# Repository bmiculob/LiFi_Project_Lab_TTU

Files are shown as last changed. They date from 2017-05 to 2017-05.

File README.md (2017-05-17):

# LiFi_Project_Lab_TTU
This a git repository containing source code as well as schematics for the Li-Fi project at Texas Tech.

Sponsored by Dr. Zhaoyang Fan
# System Operating Instructions.
1.	Adjust the transmitter and the receiver with the lens so that the light is focused on the photodiode on the receiver side.
	*	Transmitter LED is powered with 12 V
	*	Turn the transmitter microcontroller off so that the LED remains on when powered with 12 V
2.	Keep only one microcontroller plugged into the laptop whether it be the transmitter or receiver.
3.	Got the the command prompt and type the command "mode" to determine which COM port it is and write it down or memorize it.
4.	Do the same for the other microcontroller.
5.	Open both the transmitter and receiver UI.
6.	Configure the transmitter values so that the Serial Port and Baudrate (200000) are set. All other values should remain default.
7.	Configure the receiver values so that the Serial Port and Baudrate (230414) are set. All other values should remain default.
8.	Try the test signal and see that the receiver detects it.
	*	If the indicator doesn’t work then save the data to file and check it.
9.	For transmitting a file chose a file on the transmitter side by clicking the browse button.
10.	On the receiver side choose a file path to save by clicking the browse button.
	*	Every time the path is changed the UART connection must toggle from closed state to open state.
11.	Once both UI’s are configured click the transmit button on the transmitter side to transmit the file.
12.	Once it is verified that the receiver is done transmitting close the UART connection and check if the file transmitted successfully.
# Schematics
The jumpers are referenced from the chip side of the tiva microcontroller.
## Transmitter
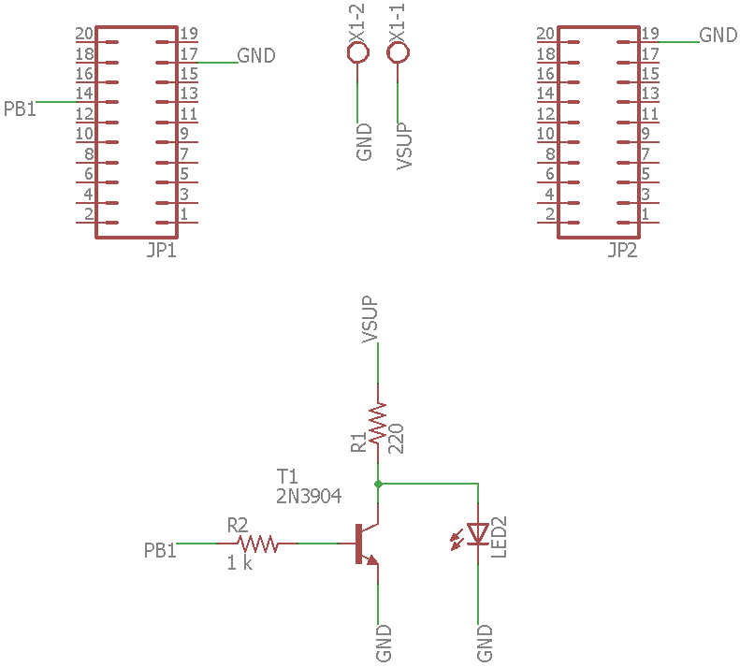
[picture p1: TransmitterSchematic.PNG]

## Receiver
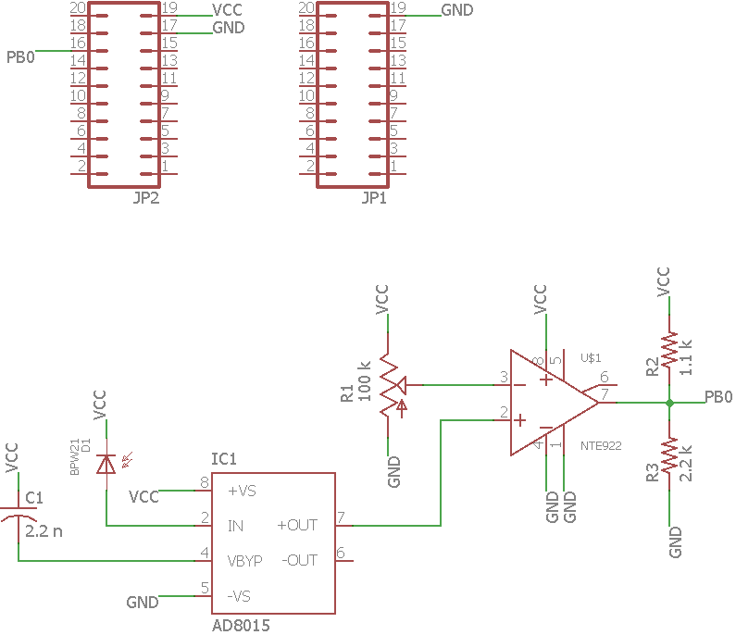
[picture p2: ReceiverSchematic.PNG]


[Transmitter]: https://github.com/soukoba/LiFi_Project_Lab_TTU/blob/master/TransmitterSchematic.PNG
[Receiver]: https://github.com/soukoba/LiFi_Project_Lab_TTU/blob/master/ReceiverSchematic.PNG

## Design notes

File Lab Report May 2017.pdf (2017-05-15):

Li-Fi Communication Prototype

Ben Miculob

IEEE # 93658299

Texas Tech University

May 2017

Sponsor Dr. Zhaoyang Fan

Group Members: Cody Cook, Joshua Bayer

Abstract

Li-Fi, an optical form of Wi-Fi communication, uses visible light to maintain

communication with other Li-Fi supported devices. A Li-Fi system consists of at least one

transmitter and one receiver. The transmitter is a system capable of sending signals through

visible light while the receiver is a system capable of receiving these signals. Li-Fi has the ability

to create wireless communication channels that will not interfere with RF frequencies.

Applicable use cases for Li-Fi would be in RF populated areas where RF is used to communicate

with equipment that is given the highest priority. The system discussed in this report focuses on

the On-Off keying modulation technique to communicate through one way transmission. There

will also be a focus on the hardware used to create the prototyped system.

Table of Contents

List of Figures

List of Tables

1 What is Li-Fi?

Li-Fi is a form of optical communication using visible light as a medium of for transferring

signals. Visible light, being a form of radiation between a wavelength of 400 nm and 700 nm,

can be an applicable medium for communication. It is naturally present within society, and can

possibly be an applicable alternative for communication. Visible light, has no chance of

interference with other signals outside its confined area. It can also be used in conjunction with

RF as these two will not interfere with each other. Advantageous applications for Li-Fi would be

on airplanes where visible light can supplement passengers with a connection to the internet

without interfering with needed communication that is installed on commercial airplanes.

Another use case would be in hospitals, as Li-Fi signals will not interfere with any medical

instruments such as MRI scanners. A good representation of the range of visible light is

illustrated in Figure 1. The numbers represent the wavelength in nanometers.

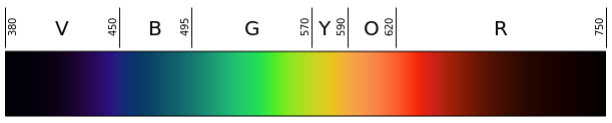
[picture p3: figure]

Figure 1: Visible Light Spectrum¹

1.1 Modulation Techniques

With Li-Fi, there are three different specifications of modulation techniques that are defined

by IEEE standards. These are the PHY, short for physical, layers called “PHY I,” “PHY II,” and

“PHY III.” This is with reference to the 7-layer OSI model used to represent network the tiers of

communication. PHY I is used for outdoor application and uses low data rates. The two main

1 By Gringer - Own work, Public Domain modulation techniques support on-off keying, and variable pulse position modulation. On-off

keying uses a sequence of high and low states to represent symbols encoded and decoded by the

symbols. In the case of PHY I, data rates go up to 100 kb/s with on off keying and use

Manchester encoded signals to send high and low states. Manchester encoded signals use

sequence of rising and falling edges to send high and low states. Figure 2 illustrates a timing

diagram demonstrating Manchester encoding. Two types of Manchester encoding are

demonstrated by this diagram. One follow’s G.E. Thomas’ encoding and the other representing

IEEE’s encoding.

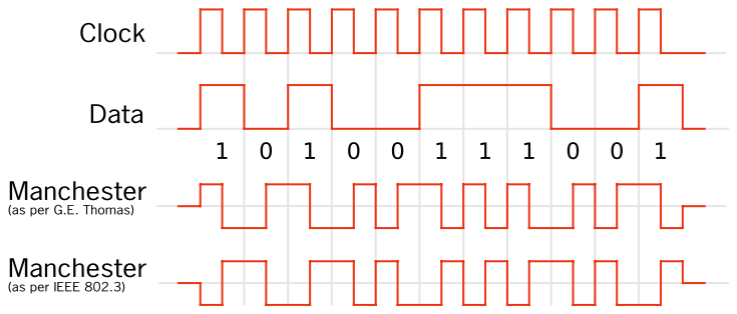
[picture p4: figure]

Figure 2: Manchester Encoding Timing Diagram Example¹

VPPM, or variable pulse position modulation, uses pulses in a specified time period to

represent high and low states in the system. These pulses are sent through the optical signal, and

the brightness of the signal determines how long the pulse must be. If the pulsed signal begins at

the start of the time period and ends between, then the represented symbol is a 0. If the pulsed

signal starts between the time period and stops at the end of the time period, then the represented

1 By Stefan Schmidt - Enhancement of Manchester Encoding, Public Domain state us a 1. Figure 3 shows a timing diagram of VPPM. This illustrates an example of different

brightness levels and their pulse lengths.

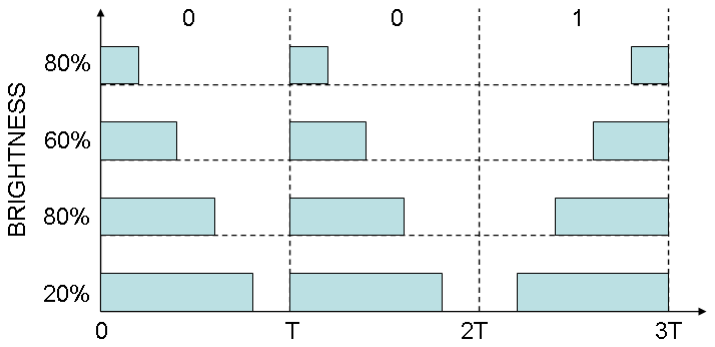
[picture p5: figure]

Figure 3: VPPM Encoding Timing Diagram Example¹

In the case of PHY I, VPPM data rates can go up to 266.6 kb/s using a 4B6B encoding.

4B6B takes 4 bit symbol and translates it into a 6 bit symbol. This is to ensure that there is an

even amount of 0’s and 1’s being sent through each encoded symbol. This helps with D.C.

balance allowing the prevention of an accumulation of charge across a coupling capacitor.

An example of a 4B6B pattern table is illustrated in Figure 4. In this case hexadecimal symbols

are translated into a 6 bit, binary pattern.

1 By gordonpovey

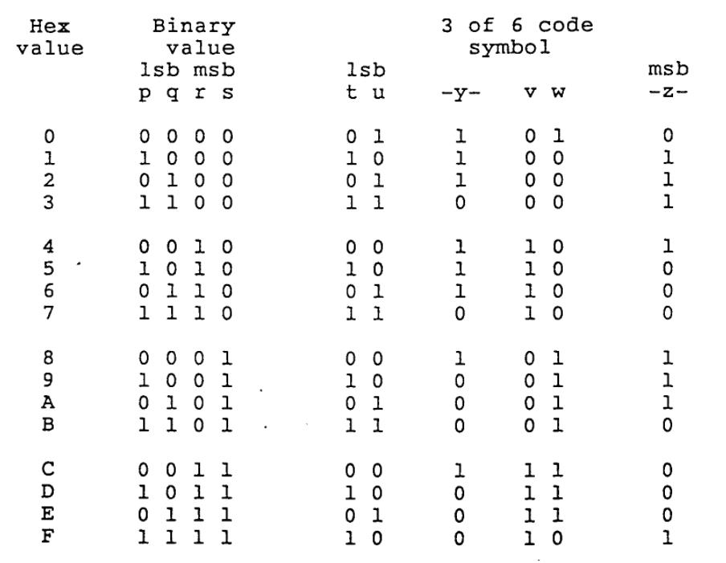
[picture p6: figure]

Figure 4: 4B6B Pattern Table¹

PHY II is used for indoor applications which also uses VPPM and OOK; however, these

have much higher data rates than PHY I. The data rates go up by an order of 10 being up to at

least 1.25 MB and up. In the case of VPPM, data rates go up to 1.25 Mb/s. With OOK, data rates

can go up to 96 Mb/s; however, on-off keying uses 8B10B encoding rather than Manchester.

8B10B is similar to 4B6B, the only difference being that it takes 8 bit patterns and translates

them into 10 bit patterns. PHY III layer is different in the case that it only uses one modulation

technique. Color shift keying is the main modulation technique used in PHY III. Its data rates

achieve a maximum speed similar to PHY II, but its initial clock rates are significantly lower.

PHY II’s minimum initial clock rate goes up to 120 MHz at its max speed, 96 Mb/s. PHY III’s

minimum clock rate goes up to 24 MHz at a max speed of 96 Mb/s. The reason that CSK is able

to achieve this is that CSK uses three channels of light to send symbols. Depending on the

1
From 4B6B Coding Scheme Patent sensitivity of the receiver, a CSK can ideally send a large amount of data at once. By encoding a

bit pattern into a color combination a CSK symbol can follow a set map of symbols. The length

of these symbols determine the type of CSK modulation used. The ones listed in the IEEE

standards are 4-CSK, or 2 bit symbols, 8- CSK, or 3 bit symbols, and 16-CSK, or 4 bit symbols.

An example of a CSK map is illustrated in Figure 5. This is shows a 16-CSK triangle being

mapped onto a color spectrum. The vertices are the primary colors red, green, and blue.

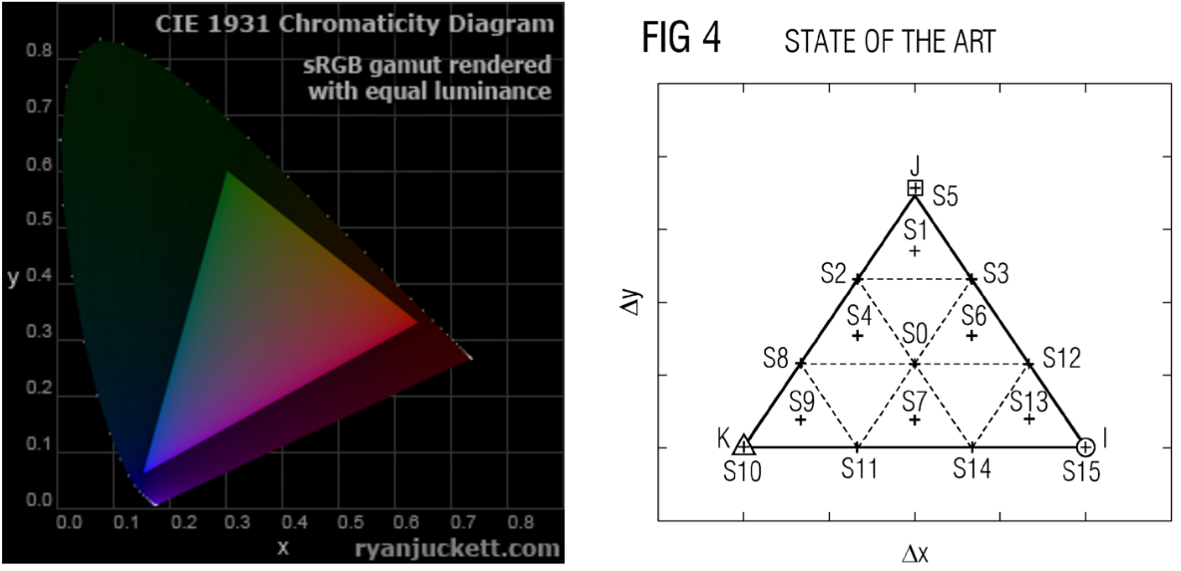
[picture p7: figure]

Figure 5: Color Map¹

and Bit Pattern Map²

The system that will be discussed focuses on on-off keying that does not use any of the

encoding standards listed in the PHY layers. The system will illustrate basic hardware and

communication between the transmitter and receiver. Techniques used in the listed PHY layers

are used as a basis for the discussed Li-Fi system. Tables 1, 2, and 3 describe all the PHY layers

and the modulation techniques used in each PHY layer.

1 PHY layer performance evaluation of the IEEE 802.15.7 visible light communication standard

2 Coding Scheme And Method For A Colour-Shift-Keying Constellation In A Visible-Light Communication System

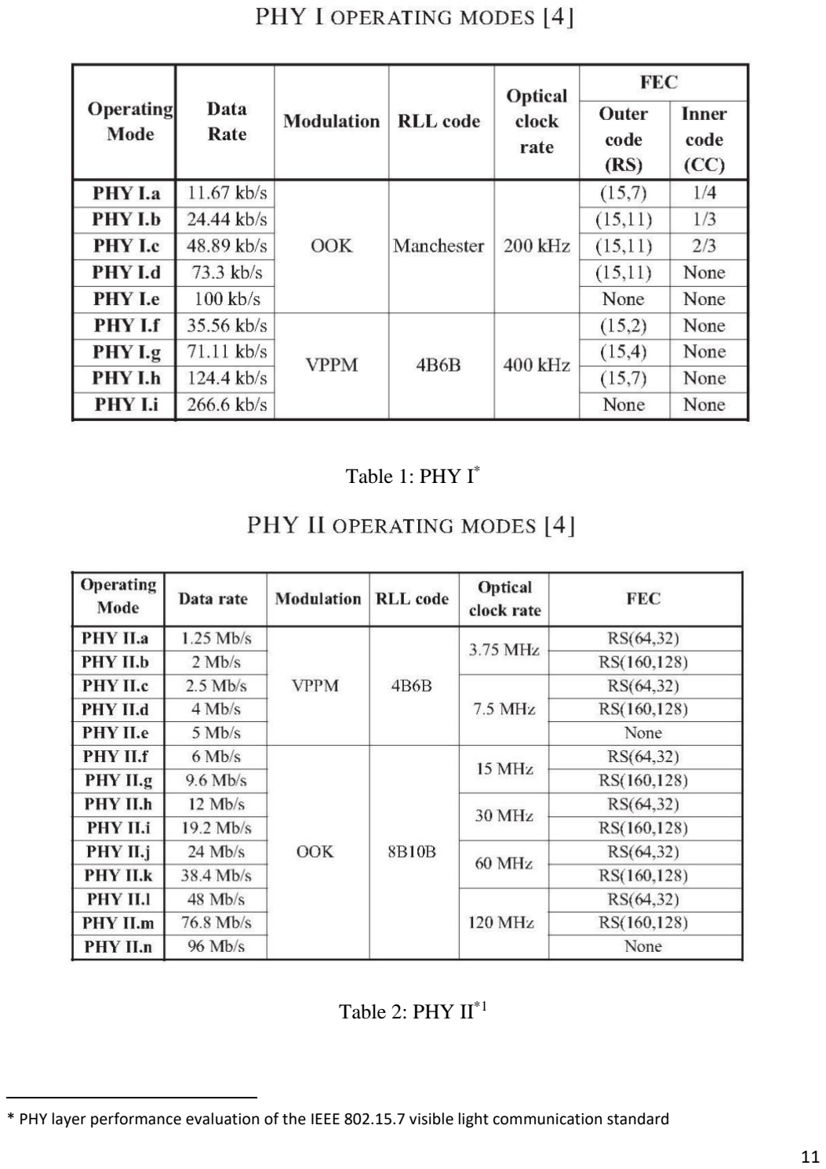
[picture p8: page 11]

Table 1: PHY I*

Table 2: PHY II*1

* PHY layer performance evaluation of the IEEE 802.15.7 visible light communication standard

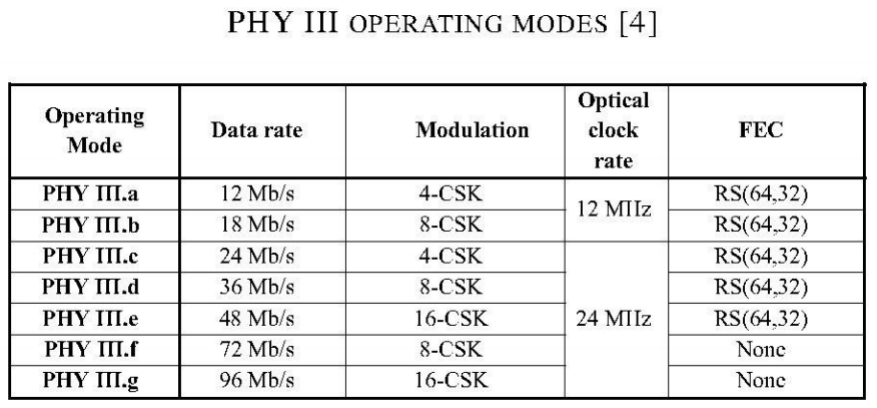
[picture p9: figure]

Table 3: PHY III*1

2 One-Way Li-Fi System

The system used to test Li-Fi communication consists of hardware only capable of one-way

communication. Creating the foundation of our prototype, the system built will test the validity

of transferring data through light. This can be tested with a simple transmitter and receiver. The

two main things required in the system is that it must be able to switch an LED, and the system

must be able to detect the LED pulses. Figure 6 illustrates a conceptual design of the system that

is considered.

* PHY layer performance evaluation of the IEEE 802.15.7 visible light communication standard

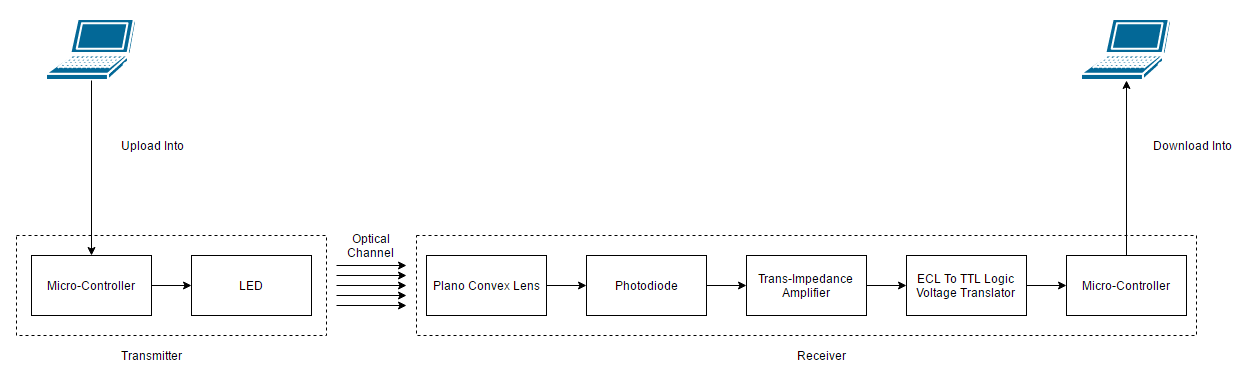
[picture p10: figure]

Figure 6: System Block Diagram

2.1 Transmitter LED Driving

Since Li-Fi uses pulsed signals to transmit data, the system must be capable of driving an

LED at a high rate. In this case, a transistor will be implemented to allow an adjustable voltage

signal to switch the LED while the supply voltage of the LED remains constant. Figure 7 shows

the schematic of the transmitter used in this system. The 220 Ω resistor limits the current going

into the LED, while it is supplied with a voltage of 12 V. Going into the base of the transistor is

the signal that will switch the LED. Our system uses a microcontroller to generate this 3.3 V

signal. The 1 kΩ resistor also acts as a current limiter for the signal. This schematic causes the

signal to be inverted, so when the signal sends a high, the LED turns off. When the signal sends a

low, the LED turns on.

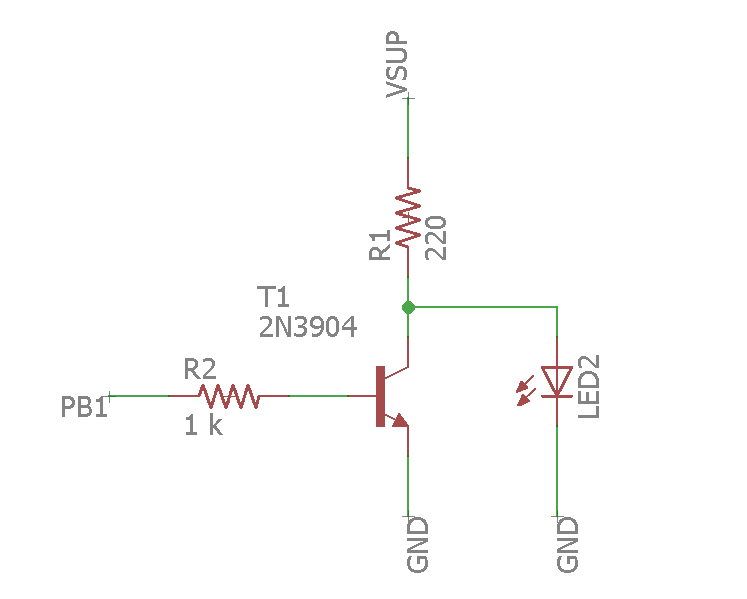
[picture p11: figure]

Figure 7: Switching LED Schematic

A board is also designed for this schematic so that it can be easily attached to a TI EK-

TM4C123GXL Launchpad, the microcontroller used in our system. Figure 8 shows the design

for this board. This board is designed for use with a square surface mount LED of about 2 mm in

length. The base is connected to PB1 of the micro controller, and pin 9 on JP1 and pin 10 on JP2

are grounded. The LED must be supplied by an independent voltage source. The dimensions are

shown in inches.

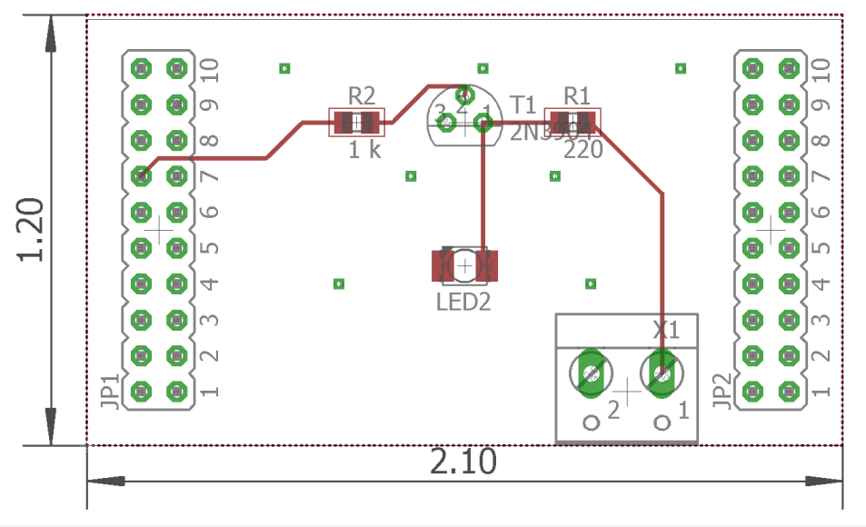
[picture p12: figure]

Figure 8: Switching LED PCB design

2.2 Receiver Photodetector

The system must be able to receive visible light signals and interpret them into signals that

the hardware will accept. A photodiode is used in this system as the photodetector for the

receiver. Figure 9 shows the schematic of the receiver used in the system. The photodiode is

reversed biased into the AD8015 which is a trans-impedance amplifier. The capacitor connected

to VBYP is used to take away noise from the power supply. According to the data sheet the

capacitor value must be chosen using formula 1. Where fmin is the minimum useful frequency.

(1) C1 >

1
2π×1000×fmin

The trans-impedance amplifier is takes the current generated by the photodiode and outputs a

differential voltage. One of the outputs of the differential is then fed into a comparator to

translate it into a logic voltage that can be used by a microcontroller. The potentiometer is used

to tune the reference voltage of the comparator. With this tested system, the voltage output of the

differential output oscillates between 3.7 V and 4.2V. The reference voltage is tuned between

these voltages to create a usable logic output. This is an open-drain comparator, so when the signal in the non-inverting output is higher than the reference voltage then the output signal is

pulled to ground. When the input signal is lower than the reference voltage then the output

voltage is voltage divided by R2 and R3. When used in conjunction with the transmitter circuit

described previously, this cancels out the inverted signal generated by the transmitter.

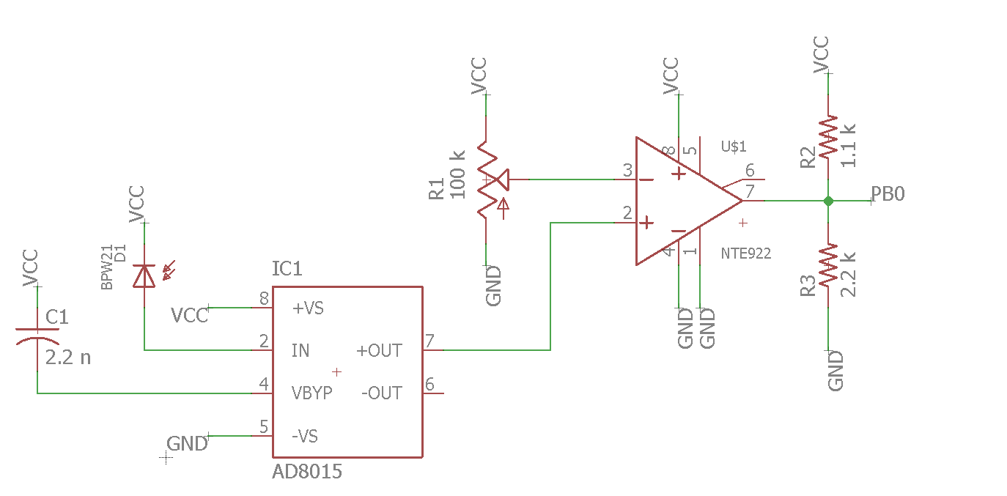
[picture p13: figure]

Figure 9: Receiver Schematic

The board design of the receiver schematic is designed while considering the pin layout

of the TI EK-TM4C123GXL Launchpad. Figure 10 shows the board design of the receiver

schematic. The circuit is powered by the microcontroller which outputs 5 V from pin 10 on JP2.

The left side of pin 8 on JP2 is where the logic is fed into from the receiver. Pin 9 on JP2 and pin

10 on JP10 are connected to the ground planes on the PCB. The board was designed for use with

a photodiode with a TO-5 package.

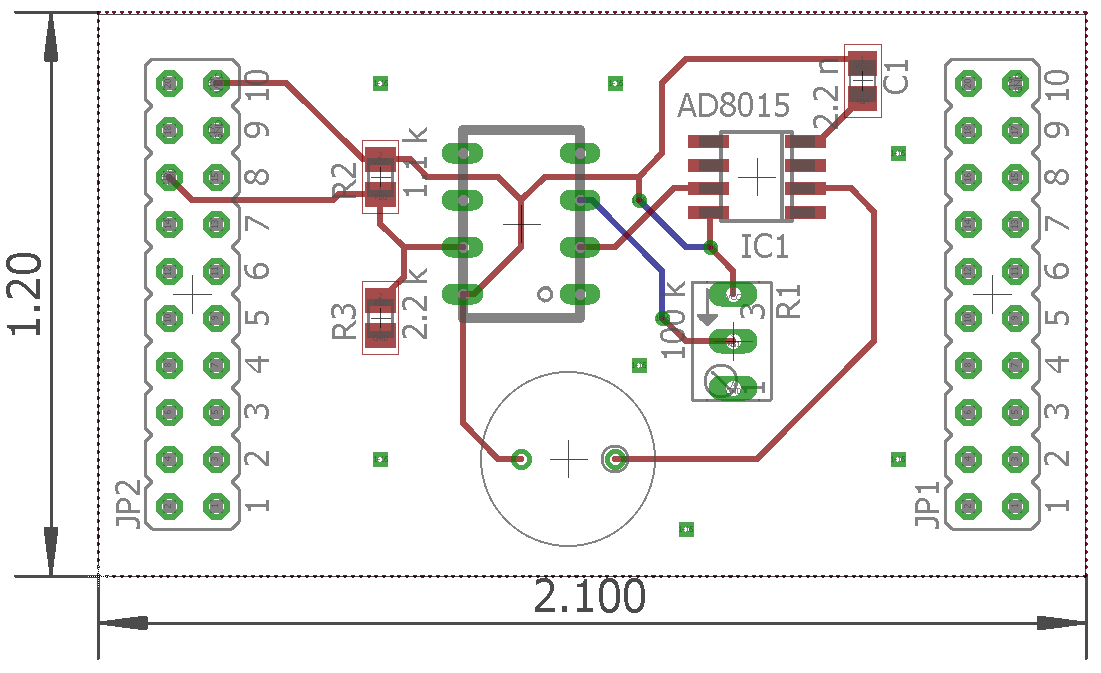
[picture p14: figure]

Figure 10: Receiver PCB Design

2.3 Microcontroller System

The current system utilizes two identical microcontrollers which are the TI EK-

TM4C123GXL Launchpad. One microcontroller drives the LED on the switching hardware. The

other will interpret the visible light signals translated from the receiver hardware. Each of them

are connected to system storage device, or a PC in this case, via a USB cord. Each Launchpad

houses a TM4C123GH6PM microcontroller, capable of generating and receiving signals in this

system. Figure 11 displays the microcontroller that is being used.

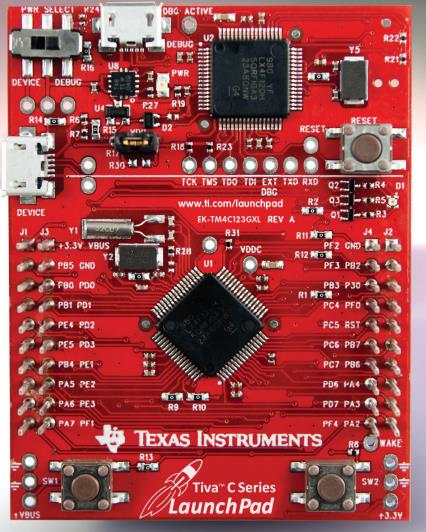
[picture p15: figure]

Figure 11: TM4C123GXL Launchpad¹

3 Communication Between System Storages and Prototyped System

Both of these microcontrollers are connected via USB to a large system storage. In this case,

a PC loaded with a Windows 10 operating system. The communication protocol used between

these components is UART. UART uses on-off keying to send packets of bits through a data

stream. UART is configured at a specific baud rate which is the amount of symbols that are sent

per period of time. Connection between the PC, microcontroller, and transmitter/receiver all use

the UART communication protocol. Figure 12 shows a simple timing diagram of 8 bit UART

communication. The start bit is a low signal for the specified time period. The stop bit is a high

signal for a specified time period. The stop bit length can be either 1, 1.5, or 2 times the time

period per bit of data.

1
From the Tiva LaunchPad Evaluation Kit PDF

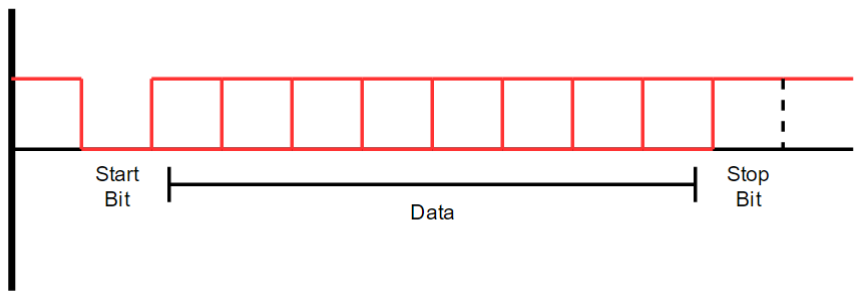
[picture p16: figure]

Figure 12: UART Diagram

Regarding the software within the microcontroller on the receiver and transmitter, there is

a queue that acts as a buffer for the data. Since the UART uses the FIFO method of sending data,

a queue is an applicable data structure for streaming bits. As bits of data are loaded into the

queue, those bits are then outputted to the specified system. Data will output into either the

transmitter, or the system storage. Figure 13 shows an example of the queue data structure. There

are head and tail indexes. The head shows where the next data should be place, while the tail

shows which data should be sent next.

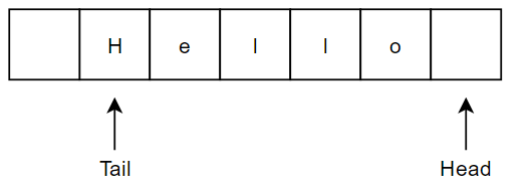
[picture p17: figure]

Figure 13: Queue Data Structure

3.1 System Data to Transmitter Output

Using the communication protocol implemented, the user will be able to load data into the

transmitter via the UART communication protocol. Since a file, at its most basic components, is a sequence of binary patterns, translating the data into a signal is not complex. The system is able

to take the file as is, and translate it to an on-off keying sequence. Data is read through in

sections of bytes, so the UART communication will send the data in packets of 8 bits. Figure 14

illustrates a flowchart of how data streaming system will work on the transmitter side. In this

case the file transfer starts with the user selecting a file and transmitting it. It takes the file and

splits it into UART packets, then it transmits each of those packets till it reaches the end of the

file.

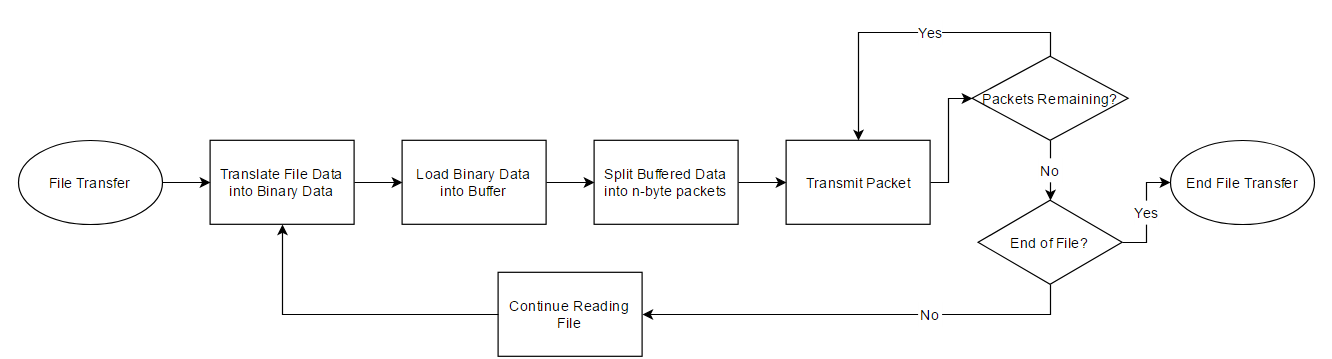
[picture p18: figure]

Figure 14: File Transfer Flowchart

In order to make this process simple for the user, a UI can be implemented in the system.

Figure 15 shows the UI designed for testing the transmitter side of the system. The user is able to

configure which port the microcontroller is connected to. The user must set the baud rate at

which the microcontroller is set to. The data bits and stop bits also must be configured at which

the microcontroller is set to. The test button allows the user to send a test signal to verify if data

is able to be streamed. The user is able to browse the system storage and choose a file to

transmit. Once the file is choose the user must use the transmit button to transmit the file through

the transmitter.

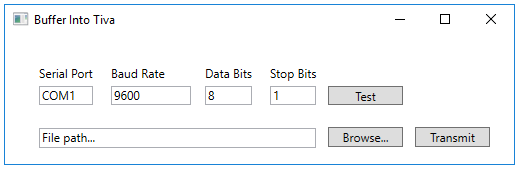
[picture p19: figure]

Figure 15: Transmitter UI

3.2 Receiver Input to System Storage

The storage system connected to the Li-Fi prototyped system will be able to receive and save

data from the receiver. This also uses the UART communication protocol which gets data from

the receiver and saves it onto the system storage. Figure 16 shows this process of taking data and

saving it to the storage. The UART communication is implemented between the two diamond

blocks representing the stop bit and start bit. It writes each of these packets to the system storage

as soon as the packet is received.

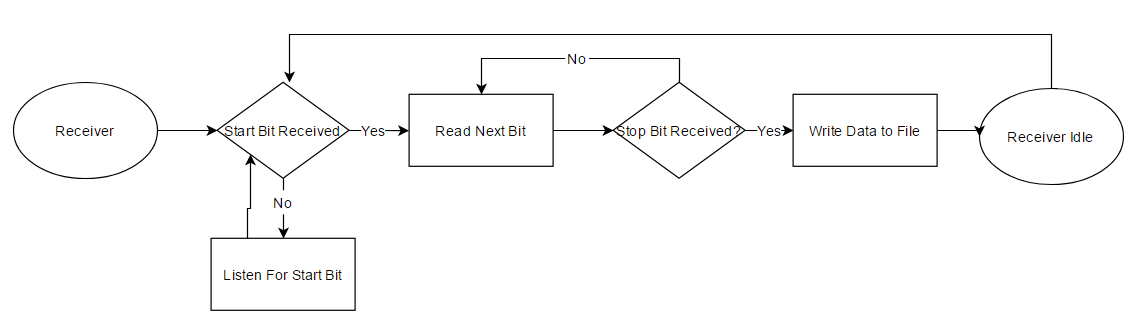
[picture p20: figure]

Figure 16: Receiver Flow Chart

A UI is implemented for the receiver to promote ease of access to the system. Figure 17

shows the UI that is used to get the file data. The same as the transmitter UI, the user is able to

configure the serial port, baud rate, data bits, and stop bits. Once this is configured, the user must

select a file path to save it to using the browse button. The user can also type the file path manually. Once all of this is configured, the user must toggle the connection open to generate

space for the file. The Incoming Data box shows the data being received in pure ASCII format.

There is also a grey box to indicate whether or not it is still receiving data. The box turns green

while data is being received by the receiver. Once it has been verified that the data transmission

has ended, the user must toggle the connection closed in order to save the file. The clear button

allows the user to clear the incoming data text box for any other file transfers.

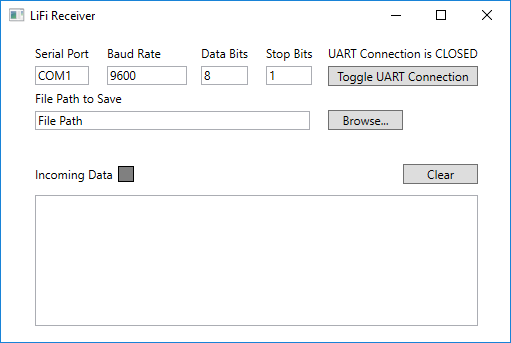
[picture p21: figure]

Figure 17: Receiver UI

4 Conclusion

According to the prototyped system, Li-Fi is a valid means of communication. The system is

able transmit and receive files via one way transmission at a rate of 200 kb/s or 25 kB/s at a

distance of 2 feet. In order to make this a true Li-Fi system the transmitter and receiver must now

be converted into transceivers. Wi-Fi uses two-way communication to reliably transfer data and

maintain connection. More improvements could be made to this system. For example, instead of

using a comparator to translate the voltage differential, use a differential amplifier to amplify the voltage difference outputted from the trans-impedance amplifier. This will take away the

required tweaking of the potentiometer on the receiver schematic. Even so, the system is capable

of one-way communication through visible light and is able to transfer files reliably at a

relatively short range.

References

1. Visible Light Spectrum Figure:

https://commons.wikimedia.org/w/index.php?curid=4639774

2. Manchester Timing Diagram Figure:

https://commons.wikimedia.org/w/index.php?curid=4639774

3. VPPM Timing Diagram Figure:

http://visiblelightcomm.com/an-ieee-standard-for-visible-light-communications/vppm/

4. 4B6B Coding Scheme Patent:

https://www.google.com/patents/EP0629068A1

5. PHY layer performance evaluation of the IEEE 802.15.7 visible light communication standard:
http://ieeexplore.ieee.org/document/6777772/
6. Coding Scheme And Method For A Colour-Shift-Keying Constellation In A Visible-Light Communication System Patent: https://www.google.com/patents/US20130308955
7. Tiva™ C Series TM4C123G LaunchPad Evaluation Kit:

http://www.ti.com/lit/ml/spmt281a/spmt281a.pdf

Appendix A

Gantt Chart

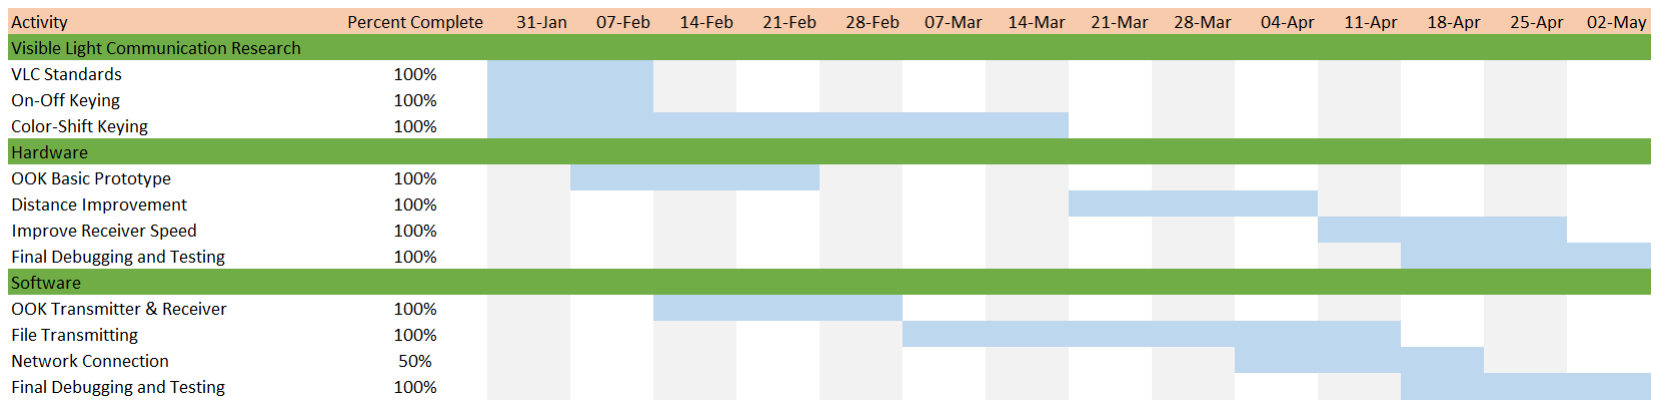
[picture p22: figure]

Appendix B

Budget

Component | Amount | Price per component | Total cost of components
Microcontroller - MSP430 | 2 | $12.99 | $25.98
Photodiode - BPW 21 | 2 | $9.38 | $18.76
LDE - L1C1-GRN1000000000 | 5 | $2.73 | $13.65
EK-TM4C123GXL (http://www.ti.com/tool/ek-tm4c123gxl) (Tiva Launchpad) | 2 | $12.99 | $25.98
AD8656 (Amplifier) | 2 | $3.45 | $6.90
Staff | Hours | Hourly wage | Total
Engineer 1 | 280 | $20.00 | $5,600
Engineer 2 | 280 | $20.00 | $5,600
Engineer 3 | 280 | $20.00 | $5,600
| | | Grand Total
| | | $16,891.27

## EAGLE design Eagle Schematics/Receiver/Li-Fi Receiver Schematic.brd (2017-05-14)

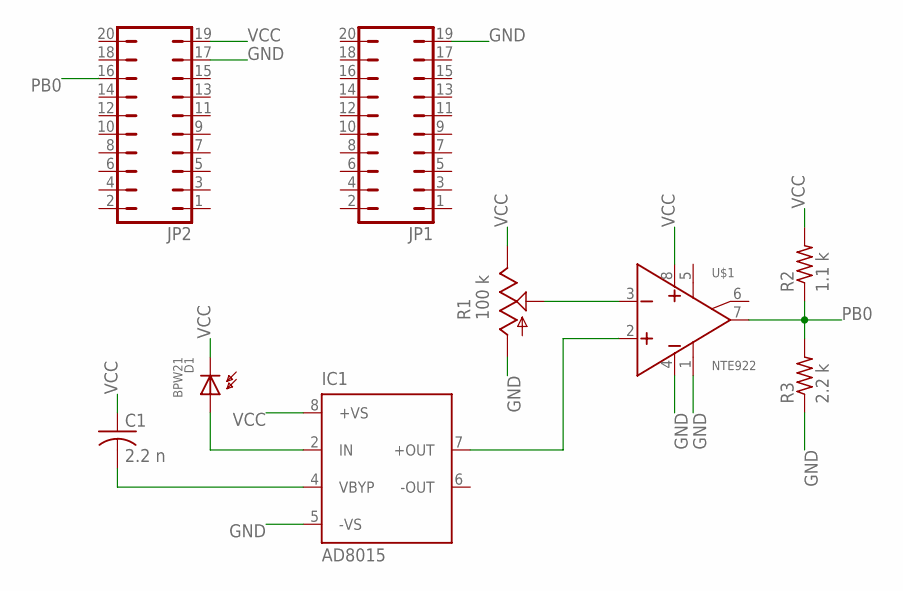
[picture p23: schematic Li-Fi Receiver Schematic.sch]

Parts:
C1: 2.2 n; C0805
D1: BPW21; TO-5
IC1: AD8015; SO8
JP1, JP2: JP10Q
R1: 100 k; B64Y
R2: 1.1 k; M0805
R3: 2.2 k; M0805
U$1: NTE922; DIP8

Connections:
GND: IC1.5 (-VS), JP1.19, JP2.17, R1.A, R3.1, U$1.1, U$1.4
unnamed: R1.S, U$1.3
unnamed: IC1.7 (+OUT), U$1.2
unnamed: D1.AN, IC1.2 (IN)
unnamed: C1.2, IC1.4 (VBYP)
PB0: JP2.16, R2.1, R3.2, U$1.7
VCC: C1.1, D1.CATH, IC1.8 (+VS), JP2.19, R1.E, R2.2, U$1.8

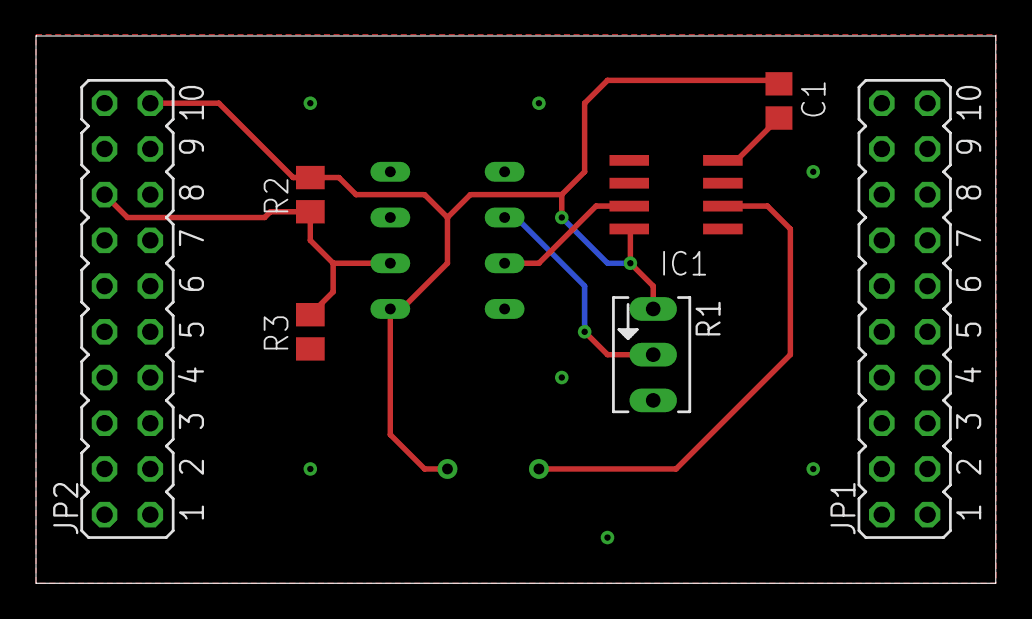
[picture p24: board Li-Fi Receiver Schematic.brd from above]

Board: 2 copper layers, 53.3 x 30.4 mm, 9 parts (0 on the bottom side), 7 nets.

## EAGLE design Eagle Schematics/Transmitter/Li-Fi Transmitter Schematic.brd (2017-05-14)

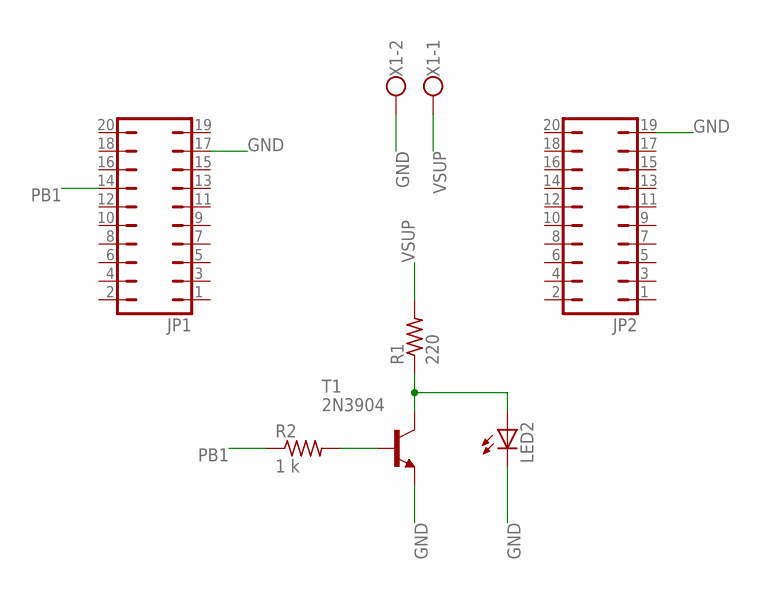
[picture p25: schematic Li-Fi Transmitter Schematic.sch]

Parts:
JP1, JP2: JP10Q
LED2: LEDKA-3528ASYC; KA-3528ASYC
R1: 220; R0805
R2: 1 k; R0805
T1: 2N3904; TO92
X1: W237-102

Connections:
GND: JP1.17, JP2.19, LED2.C, T1.3 (E), X1.2
unnamed: R2.2, T1.2 (B)
unnamed: LED2.A, R1.1, T1.1 (C)
PB1: JP1.14, R2.1
VSUP: R1.2, X1.1

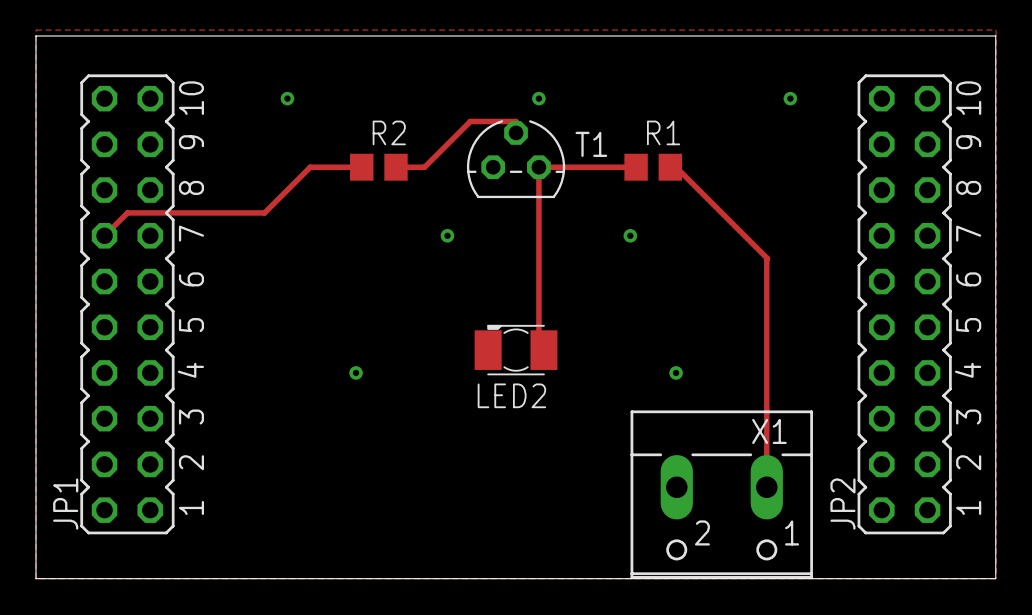
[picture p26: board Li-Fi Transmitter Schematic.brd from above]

Board: 2 copper layers, 53.3 x 30.1 mm, 7 parts (0 on the bottom side), 5 nets.

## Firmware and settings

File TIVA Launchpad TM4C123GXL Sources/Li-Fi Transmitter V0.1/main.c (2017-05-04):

//*****************************************************************************
//
// uart_echo.c - Example for reading data from and writing data to the UART in
//               an interrupt driven fashion.
//
// Copyright (c) 2012-2016 Texas Instruments Incorporated.  All rights reserved.
// Software License Agreement
//
// Texas Instruments (TI) is supplying this software for use solely and
// exclusively on TI's microcontroller products. The software is owned by
// TI and/or its suppliers, and is protected under applicable copyright
// laws. You may not combine this software with "viral" open-source
// software in order to form a larger program.
//
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
// This is part of revision 2.1.3.156 of the EK-TM4C123GXL Firmware Package.
//
//*****************************************************************************

#include <stdint.h>
#include <stdbool.h>
#include <string.h>
#include "inc/hw_ints.h"
#include "inc/hw_memmap.h"
#include "driverlib/debug.h"
#include "driverlib/fpu.h"
#include "driverlib/gpio.h"
#include "driverlib/interrupt.h"
#include "driverlib/pin_map.h"
#include "driverlib/rom.h"
#include "driverlib/sysctl.h"
#include "driverlib/uart.h"

#define MAX 300

char charArray[MAX];
int head = 0;
int tail = -1;
int itemCount = 0;

char peek(void);
char isEmpty(void);
char isFull(void);
int size(void);
void enqueue(char data);
char dequeue(void);

//*****************************************************************************
//
//! \addtogroup example_list
//! <h1>UART Echo (uart_echo)</h1>
//!
//! This example application utilizes the UART to echo text.  The first UART
//! (connected to the USB debug virtual serial port on the evaluation board)
//! will be configured in 115,200 baud, 8-n-1 mode.  All characters received on
//! the UART are transmitted back to the UART.
//
//*****************************************************************************

//*****************************************************************************
//
// The error routine that is called if the driver library encounters an error.
//
//*****************************************************************************
#ifdef DEBUG
void
__error__(char *pcFilename, uint32_t ui32Line)
{
}
#endif

//*****************************************************************************
//
// The UART interrupt handler.
//
//*****************************************************************************
void //This is for files
UARTIntHandler(void)
{
    uint32_t ui32Status;

    //
    // Get the interrrupt status.
    //
    ui32Status = UARTIntStatus(UART0_BASE, true);

    //
    // Clear the asserted interrupts.
    //
    UARTIntClear(UART0_BASE, ui32Status);

    //
    // Loop while there are characters in the receive FIFO.
    //
    while(UARTCharsAvail(UART0_BASE))
    {
        //Put character into a buffer

        enqueue(UARTCharGetNonBlocking(UART0_BASE));
    }

}

void
LiFiIntHandler(void)
{
    uint32_t ui32Status;

    ui32Status = UARTIntStatus(UART1_BASE, true);

    UARTIntClear(UART1_BASE, ui32Status);
    /*
    while(UARTCharsAvail(UART1_BASE))
    {
        //Put character into a buffer
    }*/

}

//*****************************************************************************
//
// Send a string to the UART.
//
//*****************************************************************************

LiFiSendChar(uint8_t pui8Buffer){

    UARTCharPutNonBlocking(UART1_BASE, pui8Buffer++);
    while(UARTBusy(UART1_BASE)); //Wait for buffer to clear
}

//*****************************************************************************
//
// This example demonstrates how to send a string of data to the UART.
//
//*****************************************************************************
int
main(void)
{
    //
    // Enable lazy stacking for interrupt handlers.  This allows floating-point
    // instructions to be used within interrupt handlers, but at the expense of
    // extra stack usage.
    //
    FPUEnable();

    FPULazyStackingEnable();

    //
    // Set the clocking to run directly from the crystal.
    //
    SysCtlClockSet(SYSCTL_SYSDIV_1 | SYSCTL_USE_OSC | SYSCTL_OSC_MAIN |
                       SYSCTL_XTAL_16MHZ);

    //
    // Enable the GPIO port that is used for the on-board LED.
    //
    SysCtlPeripheralEnable(SYSCTL_PERIPH_GPIOF);

    //
    // Enable the GPIO pins for the LED (PF2).
    //
    GPIOPinTypeGPIOOutput(GPIO_PORTF_BASE, GPIO_PIN_2);

    //
    // Enable the peripherals used by this example.
    //
    SysCtlPeripheralEnable(SYSCTL_PERIPH_UART0);
    SysCtlPeripheralEnable(SYSCTL_PERIPH_UART1);
    SysCtlPeripheralEnable(SYSCTL_PERIPH_GPIOA);
    SysCtlPeripheralEnable(SYSCTL_PERIPH_GPIOB);

    //
    // Enable processor interrupts.
    //
    IntMasterEnable();

    //
    // Set GPIO A0 and A1 as UART pins.
    //

    GPIOPinConfigure(GPIO_PA0_U0RX);
    GPIOPinConfigure(GPIO_PA1_U0TX);
    GPIOPinTypeUART(GPIO_PORTA_BASE, GPIO_PIN_0 | GPIO_PIN_1);

    GPIOPinConfigure(GPIO_PB0_U1RX);
    GPIOPinConfigure(GPIO_PB1_U1TX);
    GPIOPinTypeUART(GPIO_PORTB_BASE, GPIO_PIN_0 | GPIO_PIN_1);
    //
    // Configure the UART for 115,200, 8-N-1 operation.
    //
    UARTConfigSetExpClk(UART0_BASE, SysCtlClockGet(), 57600,
                            (UART_CONFIG_WLEN_8 | UART_CONFIG_STOP_ONE |
                             UART_CONFIG_PAR_NONE));

    UARTConfigSetExpClk(UART1_BASE, SysCtlClockGet(), 57600,
                            (UART_CONFIG_WLEN_8 | UART_CONFIG_STOP_ONE |
                             UART_CONFIG_PAR_NONE));

    //
    // Enable the UART interrupt.
    //
    IntEnable(INT_UART0);
    IntEnable(INT_UART1);
    UARTIntEnable(UART0_BASE, UART_INT_RX | UART_INT_RT);
    UARTIntEnable(UART1_BASE, UART_INT_RX | UART_INT_RT);
    //
    // Prompt for text to be entered.
    //

    //
    // Loop forever echoing data through the UART.
    //
    while(1)
    {
        if(itemCount != 0){
            LiFiSendChar(dequeue());
        }
    }
}

char peek(){
    return charArray[head];
}

char isEmpty(){
    return itemCount == 0;
}

char isFull(){
    return itemCount == MAX;
}

int size(){
    return itemCount;
}

void enqueue(char data){
    if(!isFull()){
        if(tail == MAX-1){
            tail = -1;
        }

        charArray[++tail] = data;
        itemCount++;
    }
}


char dequeue(){
    char data = charArray[head++];

    if(head == MAX){
        head = 0;
    }

    itemCount--;
    return data;
}

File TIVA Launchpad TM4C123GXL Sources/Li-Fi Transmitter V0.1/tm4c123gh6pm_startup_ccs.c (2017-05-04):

//*****************************************************************************
//
// startup_ccs.c - Startup code for use with TI's Code Composer Studio.
//
// Copyright (c) 2012-2016 Texas Instruments Incorporated.  All rights reserved.
// Software License Agreement
// 
// Texas Instruments (TI) is supplying this software for use solely and
// exclusively on TI's microcontroller products. The software is owned by
// TI and/or its suppliers, and is protected under applicable copyright
// laws. You may not combine this software with "viral" open-source
// software in order to form a larger program.
//
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
// This is part of revision 2.1.3.156 of the EK-TM4C123GXL Firmware Package.
//
//*****************************************************************************

#include <stdint.h>
#include "inc/hw_nvic.h"
#include "inc/hw_types.h"

//*****************************************************************************
//
// Forward declaration of the default fault handlers.
//
//*****************************************************************************
void ResetISR(void);
static void NmiSR(void);
static void FaultISR(void);
static void IntDefaultHandler(void);

//*****************************************************************************
//
// External declaration for the reset handler that is to be called when the
// processor is started
//
//*****************************************************************************
extern void _c_int00(void);

//*****************************************************************************
//
// Linker variable that marks the top of the stack.
//
//*****************************************************************************
extern uint32_t __STACK_TOP;

//*****************************************************************************
//
// External declaration for the interrupt handler used by the application.
//
//*****************************************************************************
extern void UARTIntHandler(void);
extern void LiFiIntHandler(void);

//*****************************************************************************
//
// The vector table.  Note that the proper constructs must be placed on this to
// ensure that it ends up at physical address 0x0000.0000 or at the start of
// the program if located at a start address other than 0.
//
//*****************************************************************************
#pragma DATA_SECTION(g_pfnVectors, ".intvecs")
void (* const g_pfnVectors[])(void) =
{
    (void (*)(void))((uint32_t)&__STACK_TOP),
                                            // The initial stack pointer
    ResetISR,                               // The reset handler
    NmiSR,                                  // The NMI handler
    FaultISR,                               // The hard fault handler
    IntDefaultHandler,                      // The MPU fault handler
    IntDefaultHandler,                      // The bus fault handler
    IntDefaultHandler,                      // The usage fault handler
    0,                                      // Reserved
    0,                                      // Reserved
    0,                                      // Reserved
    0,                                      // Reserved
    IntDefaultHandler,                      // SVCall handler
    IntDefaultHandler,                      // Debug monitor handler
    0,                                      // Reserved
    IntDefaultHandler,                      // The PendSV handler
    IntDefaultHandler,                      // The SysTick handler
    IntDefaultHandler,                      // GPIO Port A
    IntDefaultHandler,                      // GPIO Port B
    IntDefaultHandler,                      // GPIO Port C
    IntDefaultHandler,                      // GPIO Port D
    IntDefaultHandler,                      // GPIO Port E
    UARTIntHandler,                         // UART0 Rx and Tx
    LiFiIntHandler,                         // UART1 Rx and Tx
    IntDefaultHandler,                      // SSI0 Rx and Tx
    IntDefaultHandler,                      // I2C0 Master and Slave
    IntDefaultHandler,                      // PWM Fault
    IntDefaultHandler,                      // PWM Generator 0
    IntDefaultHandler,                      // PWM Generator 1
    IntDefaultHandler,                      // PWM Generator 2
    IntDefaultHandler,                      // Quadrature Encoder 0
    IntDefaultHandler,                      // ADC Sequence 0
    IntDefaultHandler,                      // ADC Sequence 1
    IntDefaultHandler,                      // ADC Sequence 2
    IntDefaultHandler,                      // ADC Sequence 3
    IntDefaultHandler,                      // Watchdog timer
    IntDefaultHandler,                      // Timer 0 subtimer A
    IntDefaultHandler,                      // Timer 0 subtimer B
    IntDefaultHandler,                      // Timer 1 subtimer A
    IntDefaultHandler,                      // Timer 1 subtimer B
    IntDefaultHandler,                      // Timer 2 subtimer A
    IntDefaultHandler,                      // Timer 2 subtimer B
    IntDefaultHandler,                      // Analog Comparator 0
    IntDefaultHandler,                      // Analog Comparator 1
    IntDefaultHandler,                      // Analog Comparator 2
    IntDefaultHandler,                      // System Control (PLL, OSC, BO)
    IntDefaultHandler,                      // FLASH Control
    IntDefaultHandler,                      // GPIO Port F
    IntDefaultHandler,                      // GPIO Port G
    IntDefaultHandler,                      // GPIO Port H
    IntDefaultHandler,                      // UART2 Rx and Tx
    IntDefaultHandler,                      // SSI1 Rx and Tx
    IntDefaultHandler,                      // Timer 3 subtimer A
    IntDefaultHandler,                      // Timer 3 subtimer B
    IntDefaultHandler,                      // I2C1 Master and Slave
    IntDefaultHandler,                      // Quadrature Encoder 1
    IntDefaultHandler,                      // CAN0
    IntDefaultHandler,                      // CAN1
    0,                                      // Reserved
    0,                                      // Reserved
    IntDefaultHandler,                      // Hibernate
    IntDefaultHandler,                      // USB0
    IntDefaultHandler,                      // PWM Generator 3
    IntDefaultHandler,                      // uDMA Software Transfer
    IntDefaultHandler,                      // uDMA Error
    IntDefaultHandler,                      // ADC1 Sequence 0
    IntDefaultHandler,                      // ADC1 Sequence 1
    IntDefaultHandler,                      // ADC1 Sequence 2
    IntDefaultHandler,                      // ADC1 Sequence 3
    0,                                      // Reserved
    0,                                      // Reserved
    IntDefaultHandler,                      // GPIO Port J
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

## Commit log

2017-05-14 Updates UI and schematics
    [Li-Fi Receiver Schematic.brd, Li-Fi Receiver Schematic.sch, Li-Fi Transmitter Schematic.brd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]
2017-05-14 Schematic Changes
    [Li-Fi Receiver Schematic.brd]
2017-05-17 Schematic Images
2017-05-17 Updates to readme with schematics and system instructions
